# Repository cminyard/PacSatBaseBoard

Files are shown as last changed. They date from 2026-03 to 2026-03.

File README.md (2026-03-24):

# PacSatBaseBoard

This is a base board design to start with for a PacSat design, or
really any Pumpkin Space CSKB board.

To use this, pull this project up in KiCad, then do "Save As" under
the file menu and save it in a new directory to use as the starting
point for your board.  You might have to deal with the .git directory
being copied.

All local footprints go into the "footprints" directory, create symbol
libraries in the "symbols" directory as necessary.  There are already
connectors added to those.

NOTE: The CSKB standard has ESQ-126-39-G-D PC104 connectors, which
have 12.19mm pins.  This leaves around 3mm of pin exposed between the
boards.  This design has ESQ-126-38-G-D PC104 connectors, which has
7.36mm pins.  This leaves the 11.05mm as the board height, and 11.11mm
(.438") spacers are pretty common.

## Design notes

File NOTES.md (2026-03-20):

Notes on the PacSat Base Board
==============================

This keeps track of history, general information, things that need to
be done, and things that have been done.

# TODO

# Done

# History

## 2026-03-20

Initial Creation

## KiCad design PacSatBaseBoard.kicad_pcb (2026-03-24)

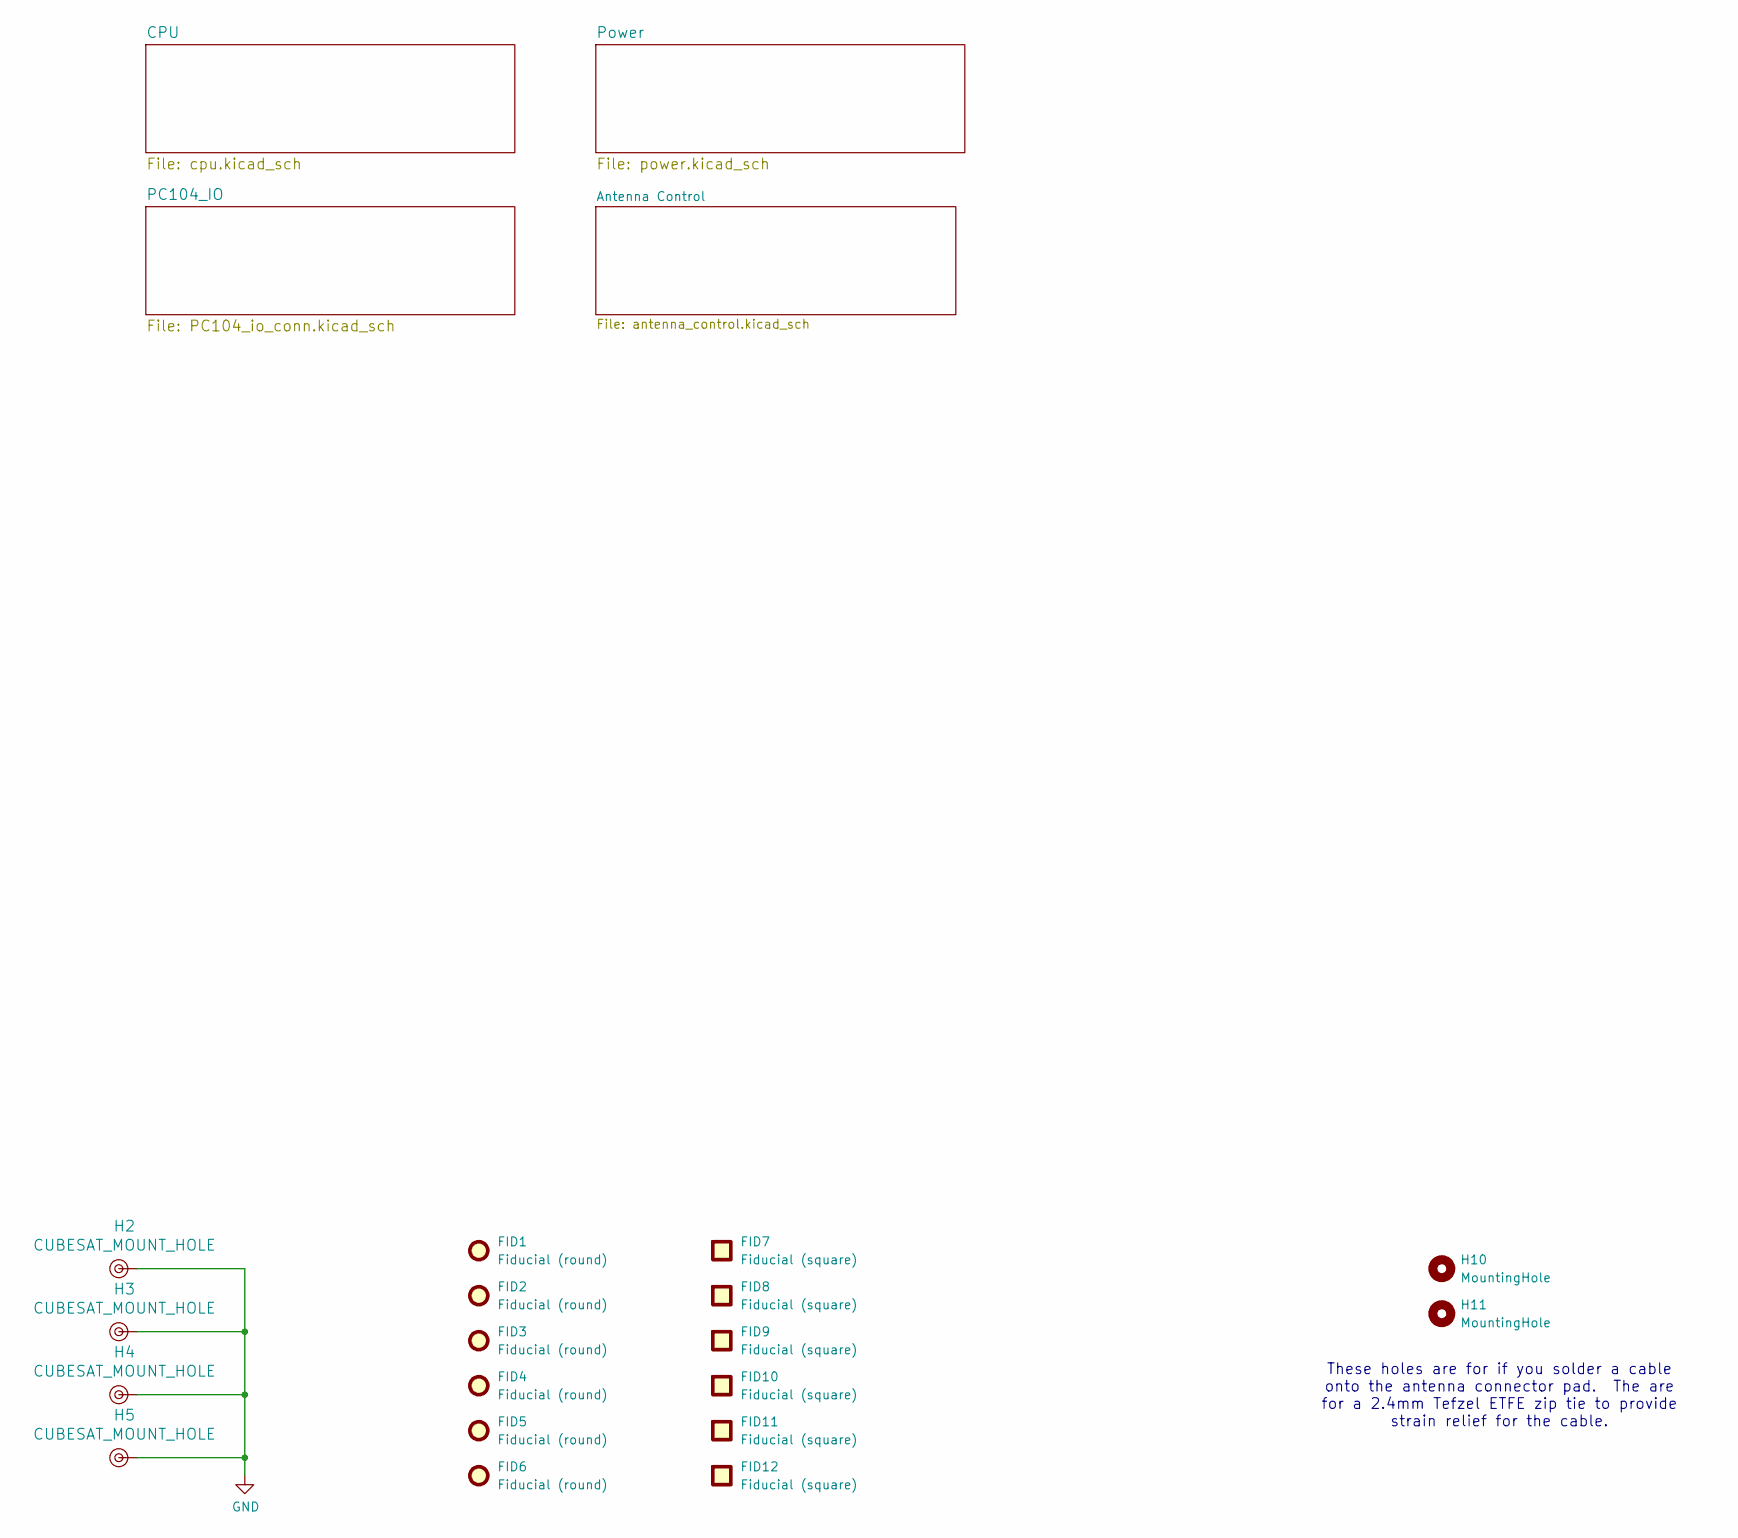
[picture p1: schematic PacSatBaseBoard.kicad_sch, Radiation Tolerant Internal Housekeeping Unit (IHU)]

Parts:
FID1, FID2, FID3, FID4, FID5, FID6: Fiducial (round); Fiducial_1mm_Mask2mm
FID7, FID8, FID9, FID10, FID11, FID12: Fiducial (square); Fiducial_Square_1mm_Mask2mm
H2, H3, H4, H5: CUBESAT_MOUNT_HOLE
H10, H11: MountingHole; MountingHole_2.7mm

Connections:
GND: H2.1, H3.1, H4.1, H5.1; also elsewhere on the board

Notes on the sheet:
These holes are for if you solder a cable onto the antenna connector pad. The are for a 2.4mm Tefzel ETFE zip tie to provide strain relief for the cable.

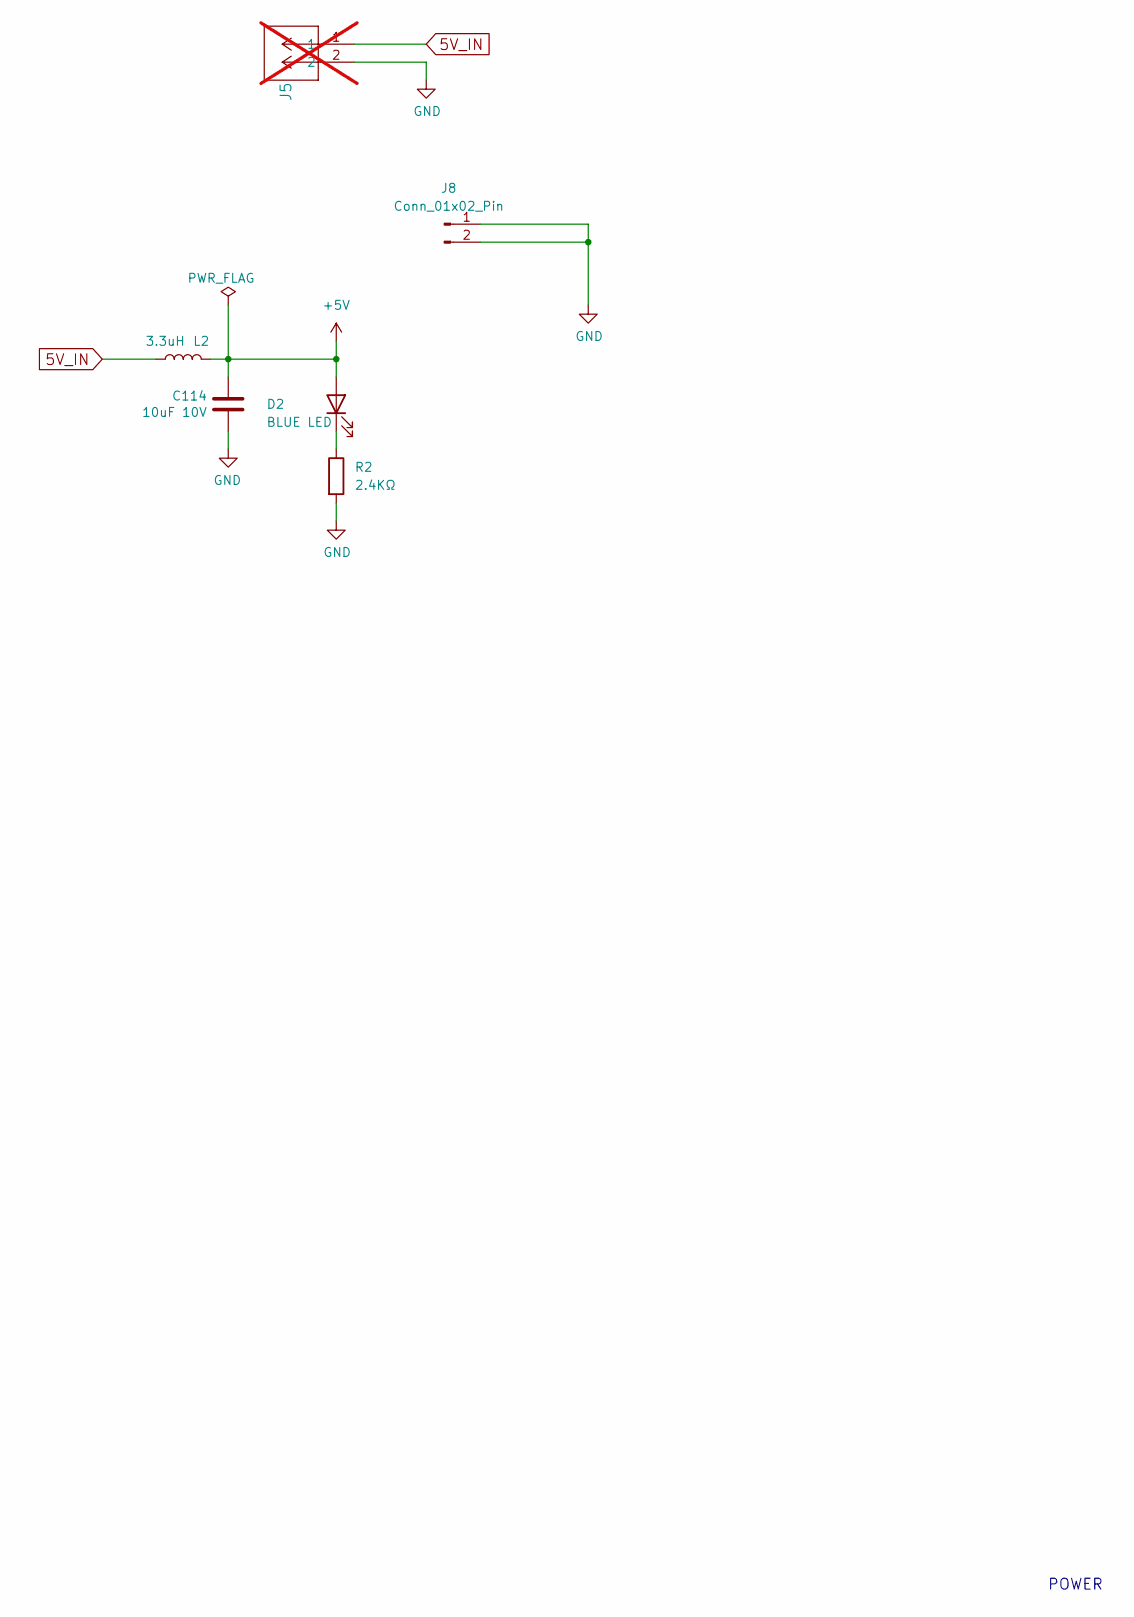
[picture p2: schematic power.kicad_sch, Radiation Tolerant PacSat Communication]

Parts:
C114: 10uF 10V; C_1206_3216Metric
D2: BLUE LED; LED_0603_1608Metric_Pad1.05x0.95mm_HandSolder
J5: HTSW-102-07-G-S; CON2_1X2_TU_TSW; not fitted
J8: Conn_01x02_Pin; SolderWire-0.5sqmm_1x02_P4.6mm_D0.9mm_OD2.1mm
L2: 3.3uH; L_1210_3225Metric_Pad1.42x2.65mm_HandSolder
R2: 2.4KΩ; R_0603_1608Metric_Pad0.98x0.95mm_HandSolder

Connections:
5V_IN: J5.1, L2.2; also elsewhere on the board
+5V: C114.1, D2.2 (A), L2.1
GND: C114.2, J5.2, J8.1, J8.2, R2.2; also elsewhere on the board
unnamed: D2.1 (K), R2.1

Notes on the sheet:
POWER

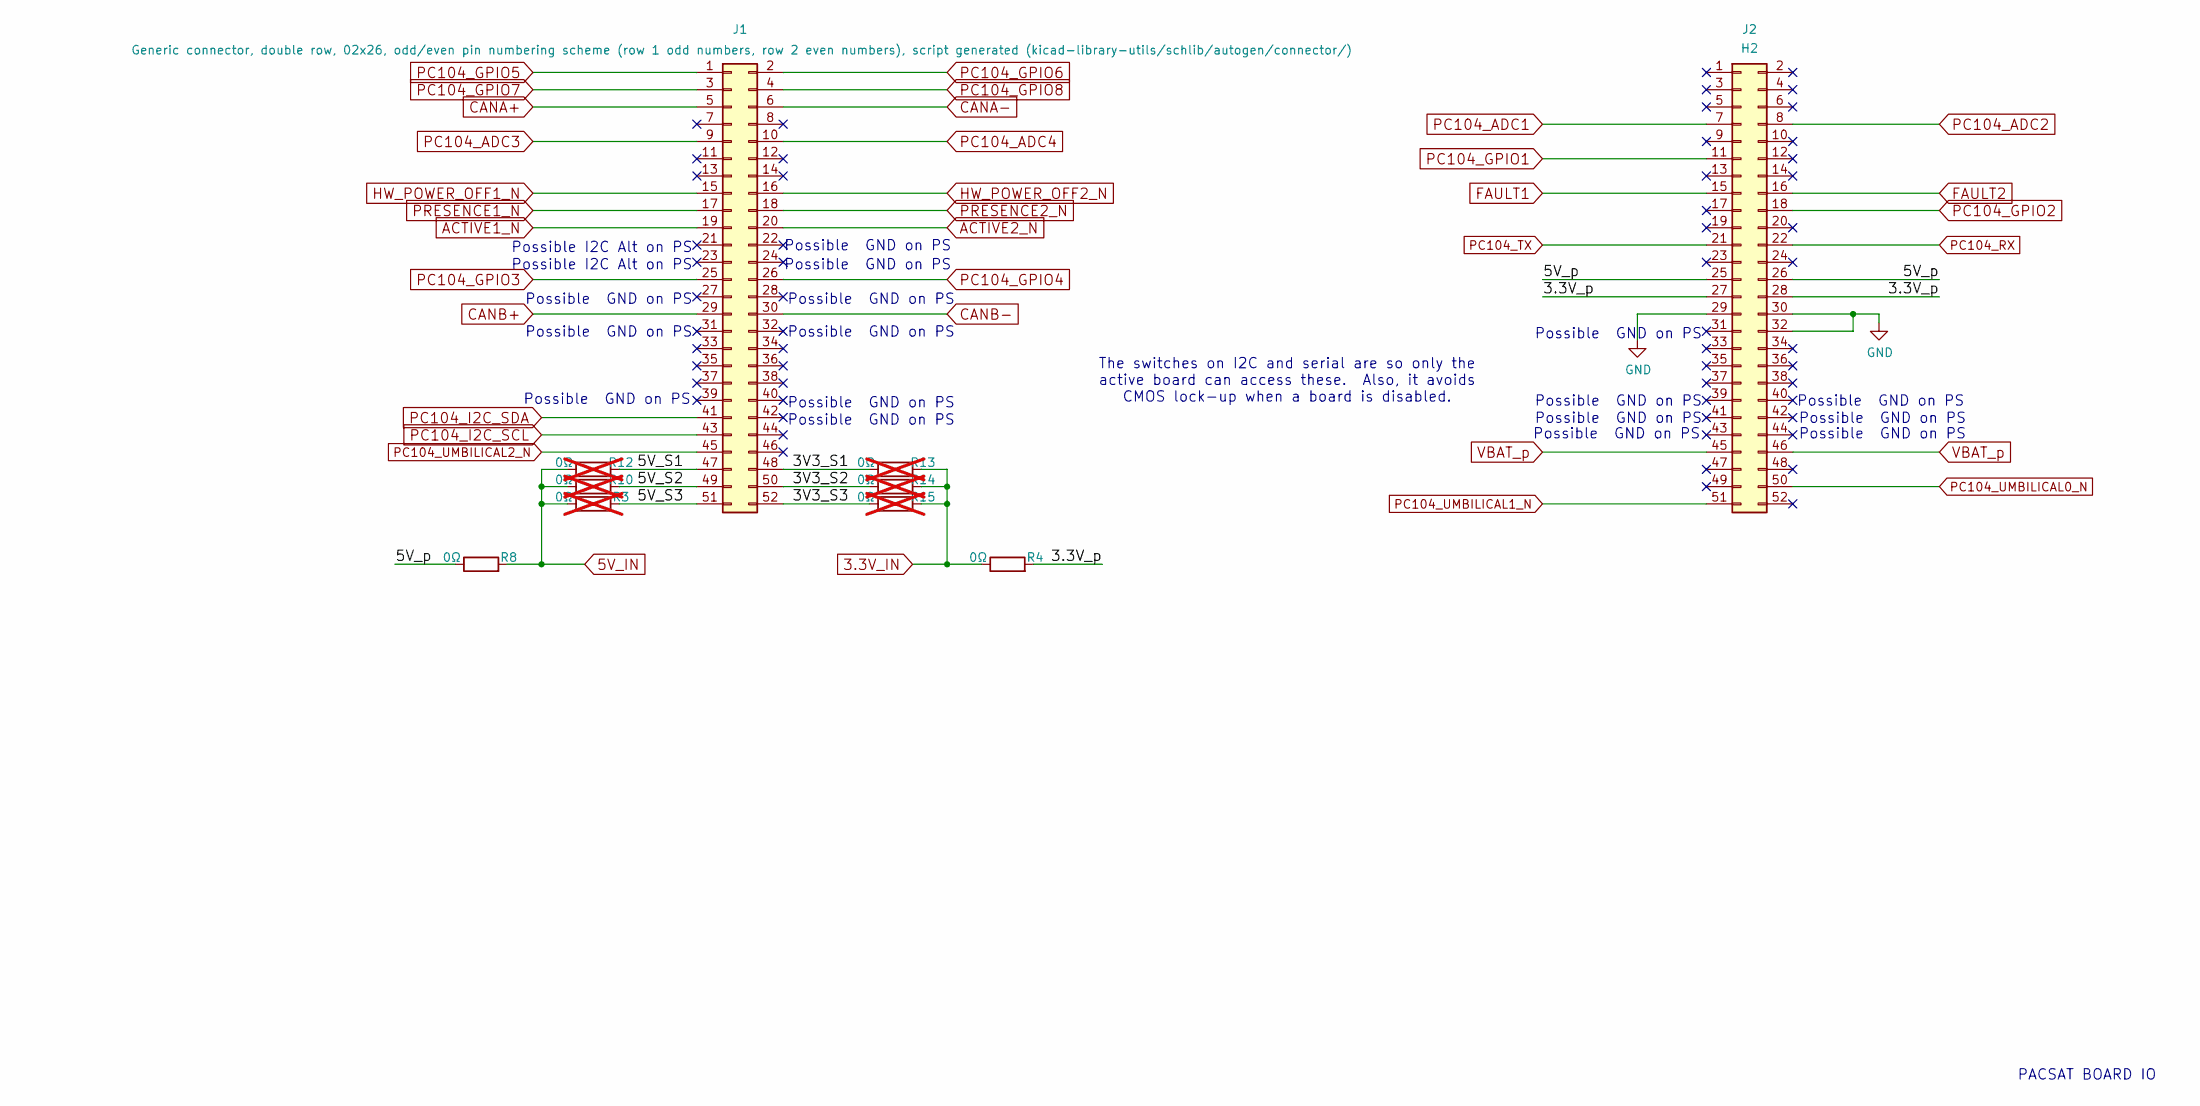
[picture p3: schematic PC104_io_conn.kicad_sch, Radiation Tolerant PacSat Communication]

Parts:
J1, J2: ESQ-126-38-G-D; CONN_ESQ-126-39-G-D_SAI
R3, R10, R12, R13, R14, R15: 0Ω; R_0603_1608Metric_Pad0.98x0.95mm_HandSolder; not fitted
R4, R8: 0Ω; R_0603_1608Metric_Pad0.98x0.95mm_HandSolder

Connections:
3.3V_IN: R4.1, R13.2, R14.2, R15.2
5V_IN: R3.1, R8.2, R10.1, R12.1; also elsewhere on the board
/PC104_IO/3.3V_p: J2.27, J2.28, R4.2
/PC104_IO/3V3_S1: J1.48, R13.1
/PC104_IO/3V3_S2: J1.50, R14.1
/PC104_IO/3V3_S3: J1.52, R15.1
/PC104_IO/5V_S1: J1.47, R12.2
/PC104_IO/5V_S2: J1.49, R10.2
/PC104_IO/5V_S3: J1.51, R3.2
/PC104_IO/5V_p: J2.25, J2.26, R8.1
ACTIVE1_N: J1.19
ACTIVE2_N: J1.20
CANA+: J1.5
CANA-: J1.6
CANB+: J1.29
CANB-: J1.30
FAULT1: J2.15
FAULT2: J2.16
GND: J2.29, J2.30, J2.32; also elsewhere on the board
HW_POWER_OFF1_N: J1.15
HW_POWER_OFF2_N: J1.16
PC104_ADC1: J2.7
PC104_ADC2: J2.8
PC104_ADC3: J1.9
PC104_ADC4: J1.10
PC104_GPIO1: J2.11
PC104_GPIO2: J2.18
PC104_GPIO3: J1.25
PC104_GPIO4: J1.26
PC104_GPIO5: J1.1
PC104_GPIO6: J1.2
PC104_GPIO7: J1.3
PC104_GPIO8: J1.4
PC104_I2C_SCL: J1.43
PC104_I2C_SDA: J1.41
PC104_RX: J2.22
PC104_TX: J2.21
PC104_UMBILICAL0_N: J2.50
PC104_UMBILICAL1_N: J2.51
PC104_UMBILICAL2_N: J1.45
PRESENCE1_N: J1.17
PRESENCE2_N: J1.18
VBAT_p: J2.45, J2.46

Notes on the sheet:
Possible GND on PS
The switches on I2C and serial are so only the active board can access these. Also, it avoids CMOS lock-up when a board is disabled.
PACSAT BOARD IO
Possible I2C Alt on PS

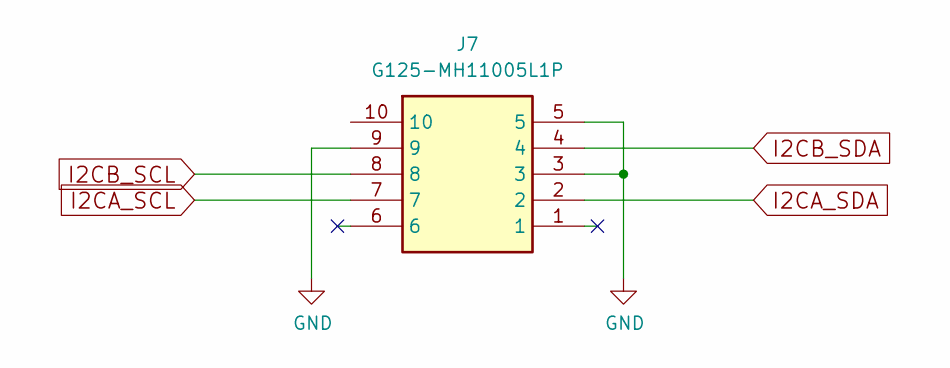
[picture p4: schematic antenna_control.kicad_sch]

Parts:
J7: G125-MH11005L1P; Manufacturer_Part_Number G125-MH11005L1P; Mouser Part Number 855-G125-MH11005L1P

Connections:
GND: J7.3, J7.5, J7.9; also elsewhere on the board
I2CA_SCL: J7.7
I2CA_SDA: J7.2
I2CB_SCL: J7.8
I2CB_SDA: J7.4

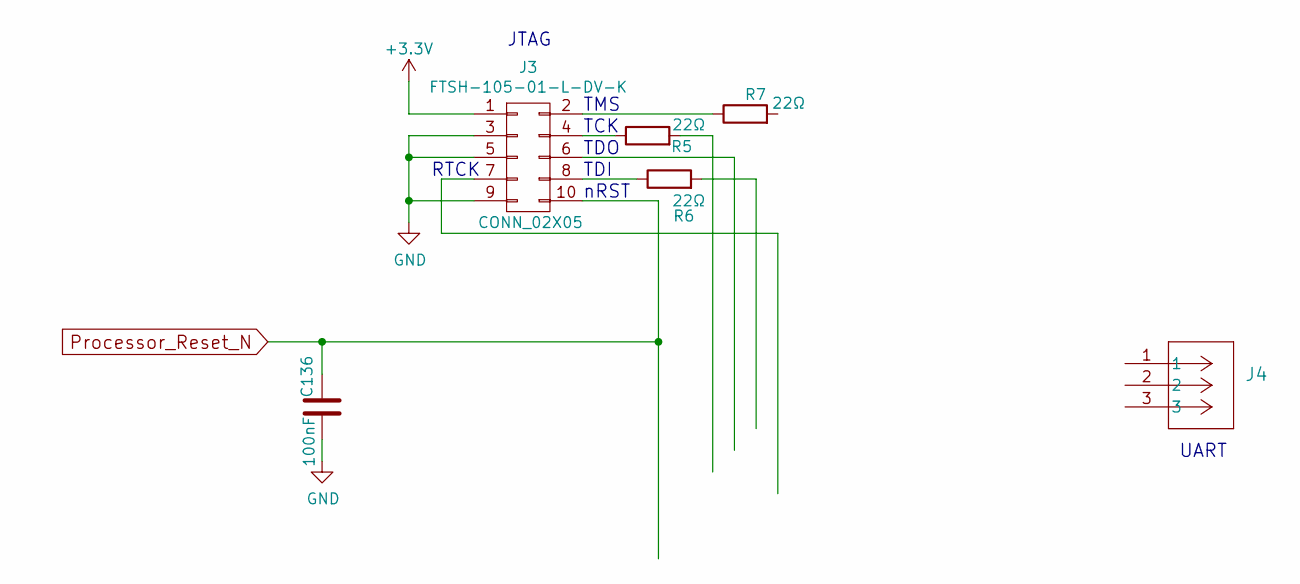
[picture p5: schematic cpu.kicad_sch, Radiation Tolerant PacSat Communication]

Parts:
C136: 100nF; C_0402_1005Metric_Pad0.74x0.62mm_HandSolder
J3: FTSH-105-01-L-DV-K
J4: TSW-103-08-F-S-RA; CON3_1X3_TR_TSW_SAI
R5, R6, R7: 22Ω; R_0402_1005Metric_Pad0.72x0.64mm_HandSolder

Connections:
+3.3V: J3.1
GND: C136.2, J3.3, J3.5, J3.9; also elsewhere on the board
unnamed: J3.2, R7.1
unnamed: J3.4, R5.1
unnamed: J3.8, R6.1
Processor_Reset_N: C136.1, J3.10

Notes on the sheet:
RTCK
UART
TCK
nRST
TDI
JTAG
TDO
TMS

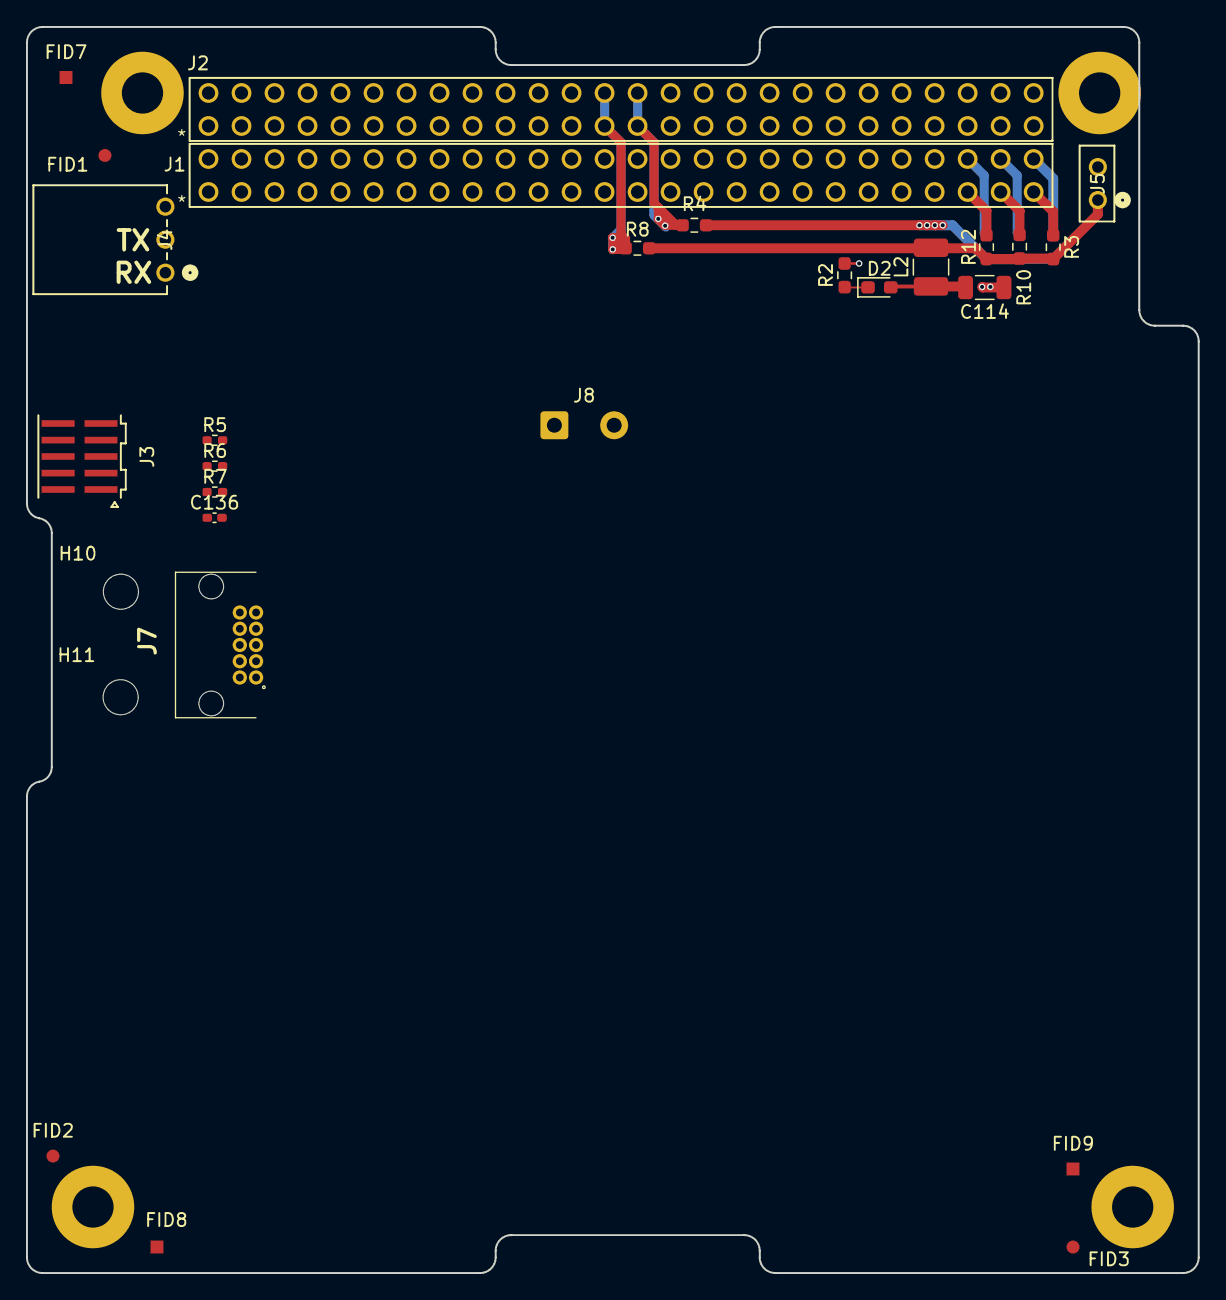
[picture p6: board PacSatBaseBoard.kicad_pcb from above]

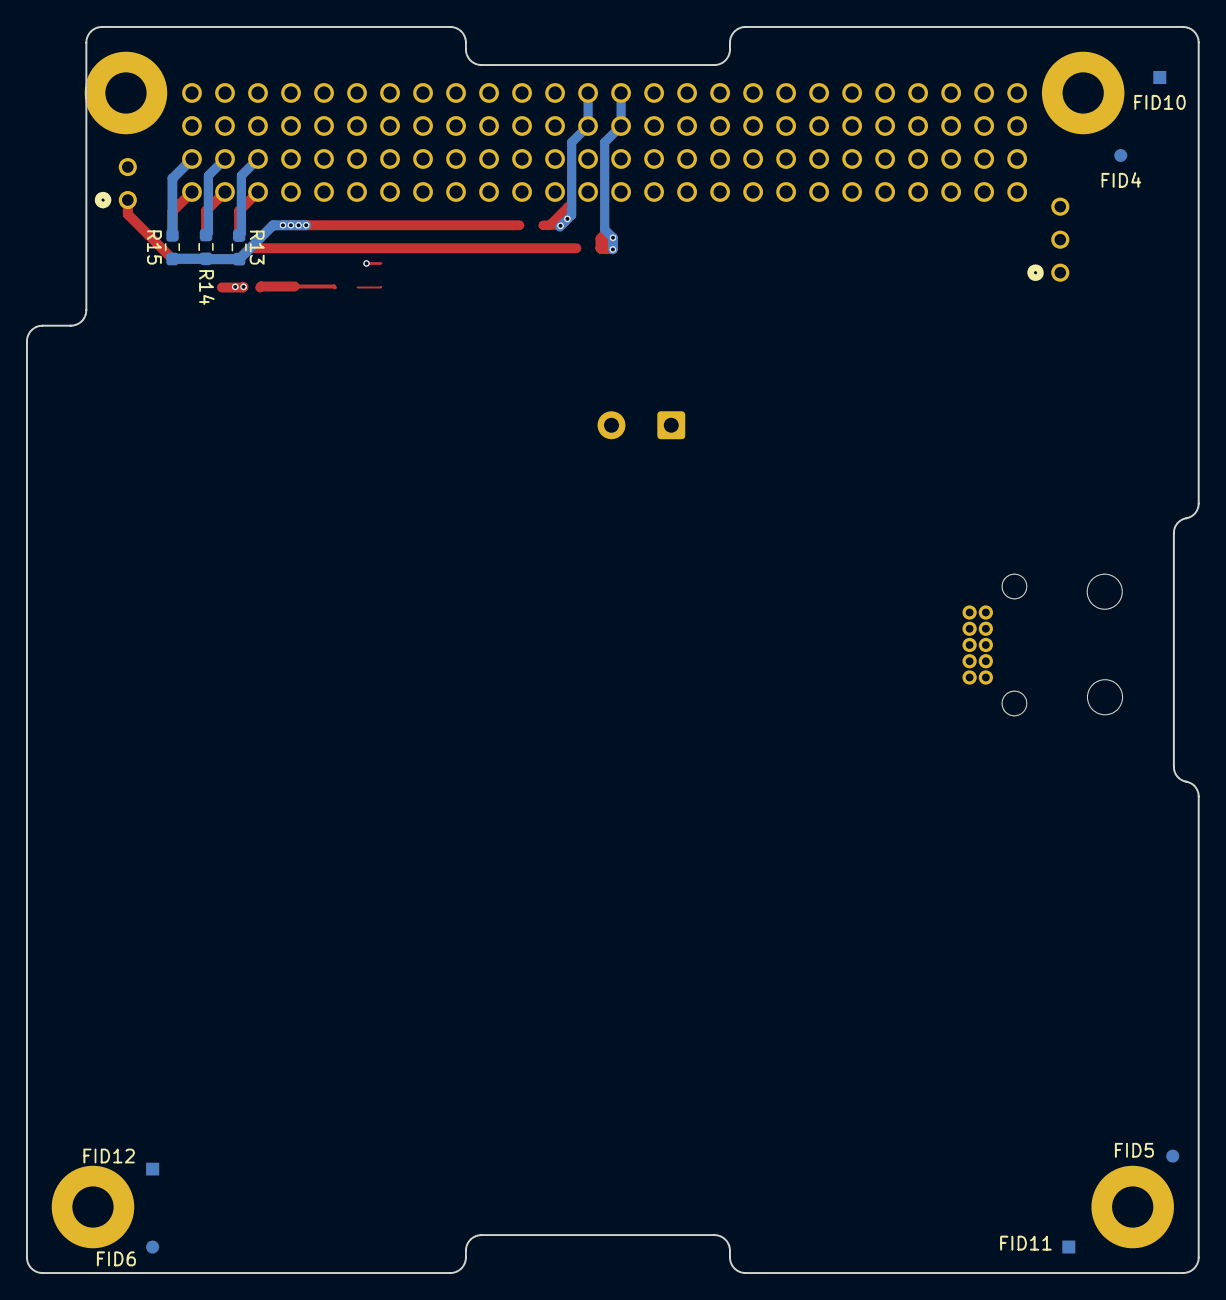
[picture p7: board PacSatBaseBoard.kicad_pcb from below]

Board: 6 copper layers, 90.2 x 95.9 mm, 41 parts (9 on the bottom side), 18 nets.

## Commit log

2026-03-20 Initial creation
    [PC104_io_conn.kicad_sch, PacSatBaseBoard.kicad_pcb, PacSatBaseBoard.kicad_sch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]
2026-03-24 Change the connector, power cleanups
    Change the PC104 connector. The CSKB specifies ESQ-126-39-G-D, which
    have 12.19mm pins. This leaves around 3mm of pin exposed between the
    boards. This design has ESQ-126-38-G-D PC104 which will leave no space.
    Rework the power to a fairly common setup.
    [PC104_io_conn.kicad_sch, PacSatBaseBoard.kicad_pcb, PacSatBaseBoard.kicad_sch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]
2026-03-24 Changes from refilling zones
    [PacSatBaseBoard.kicad_pcb]
